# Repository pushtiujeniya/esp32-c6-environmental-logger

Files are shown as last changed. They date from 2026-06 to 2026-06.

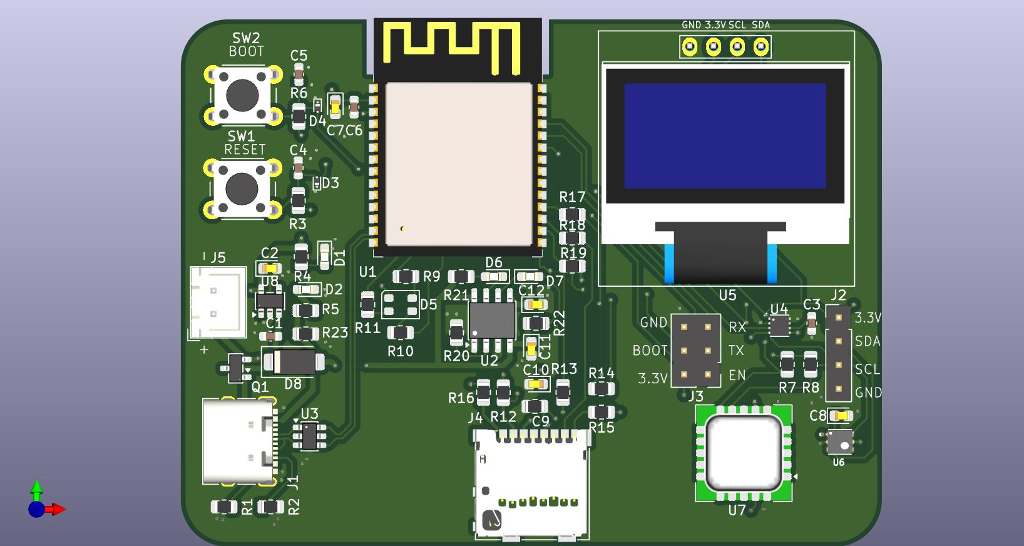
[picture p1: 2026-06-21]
3d view/3D_top view.jpg

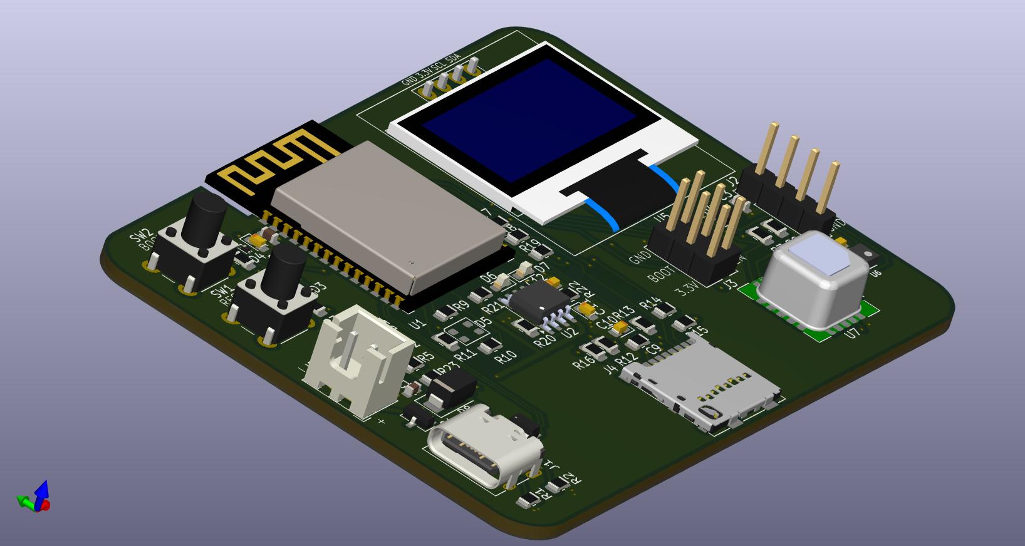
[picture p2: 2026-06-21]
3d view/3d_side view.jpg

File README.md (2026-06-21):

# ESP32-C6 Environmental Sensor Station & Data Logger

An open-source, 4-layer IoT environmental monitoring station and telemetry data logger powered by the **ESP32-C6-WROOM-1** microcontroller. This board utilizes multi-protocol wireless connectivity (Wi-Fi 6, BLE 5, and Zigbee/Thread) to read atmospheric and gas sensors, display local telemetry, and securely back up data to a local MicroSD card.

---

## 🛠 Core Features & Hardware

### 1. Processor & Wireless Connectivity
* **MCU:** ESP32-C6-WROOM-1
* **Programming/Debugging:** On-board dual-purpose interfaces for flashing and debugging via a protected USB-C 2.0 interface.
* 
### 2. Comprehensive Sensor Array
* **SCD41-D-R2:** Photoacoustic $CO_2$ sensor measuring true carbon dioxide levels in ppm ($I^2C$ Address: `0x62`).
* **SGP41-D-R4:** Digital gas sensor providing multi-pixel MOx sensing for VOC (Volatile Organic Compounds) and $NO_x$ (Nitrogen Oxides) indoor environmental indexes ($I^2C$ Address: `0x59`).
* **HDC2033:** Low-power, high-accuracy digital temperature and relative humidity sensor ($I^2C$ Address: `0x44`).

### 3. Storage & User Interface
* **MicroSD Card Slot:** Dedicated SPI-driven logging interface with individual inline trace damping resistors and pull-ups for secure local data logging.
* **OLED Display (SSD1306):** 0.96" $I^2C$ graphic display panel for live visual terminal outputs and local troubleshooting ($I^2C$ Address: `0x3C`).

### 4. Power & Battery Management
* **Charging:** TP4056 lithium battery management IC with automated charge/discharging  indicator LEDs.
* **Power Path Switching:** Automated hardware power routing utilizing an AO3401A P-Channel MOSFET to seamlessly switch between USB power and Battery power.
* **Regulator:** AP2112K-3.3V Ultra-low dropout, low-noise LDO regulator supplying clean $3.3\text{V}$ power rails up to $600\text{mA}$ to the wireless MCU and sensors.

### 5. Push Button Switch
* **Reset switch** A button with ESD protection  to reset the MCU 
* **BOOT switch** A BOOT switch button to enter into bootloading mode for new firmware flashing
  
### 5. I2C and UART Pin Connector
* External i2c pin header
* External UART pin header  

---

## 🎛 4-Layer PCB Stackup Architecture

This board is structured with an optimized 4-layer stackup:

* **Layer 1 (Top Copper - F.Cu):** High-speed digital signals, data busses ($I^2C$, SPI), and  component placement.
* **Layer 2 (Internal Plane 1 - In1.Cu):** Solid Ground Plane (GND) providing direct, uninterrupted return paths for low EMI noise and optimal RF shielding.
* **Layer 3 (Internal Plane 2 - In2.Cu):** Split Power Plane ($+5\text{V}$, $+3.3\text{V}$, $\text{VBAT}$) providing low-impedance power distribution directly below signal lines.
* **Layer 4 (Bottom Copper - B.Cu):** Secondary signal traces and clean copper pours for thermal dissipation.

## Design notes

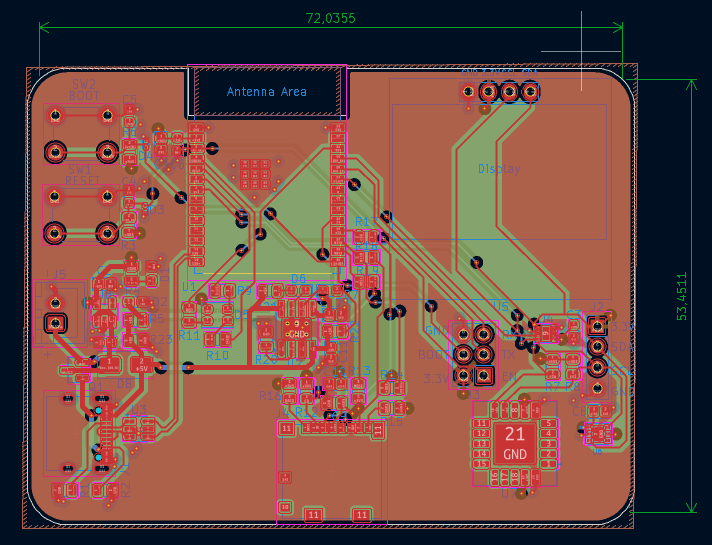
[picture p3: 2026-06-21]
layout images/Screenshot 2026-06-21 155718.png

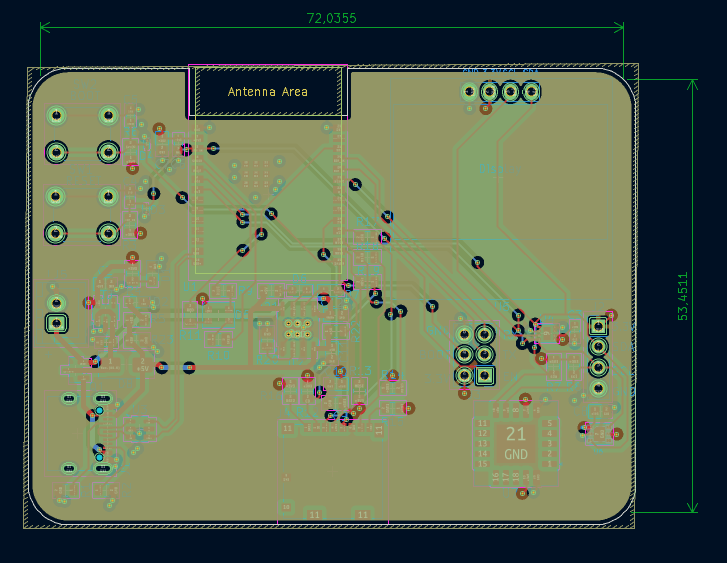
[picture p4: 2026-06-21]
layout images/Screenshot 2026-06-21 155729.png

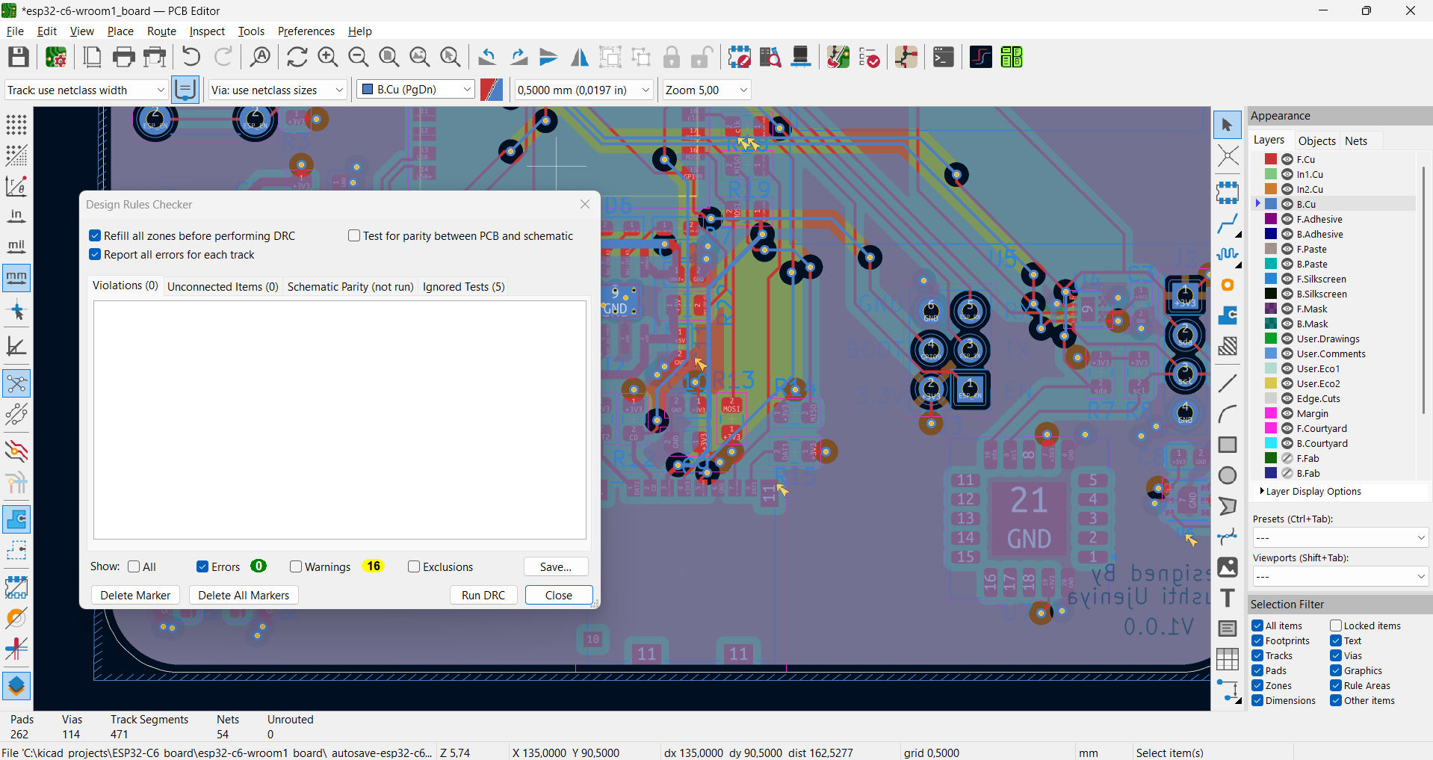
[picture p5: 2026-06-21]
layout images/Screenshot 2026-06-21 132708.png

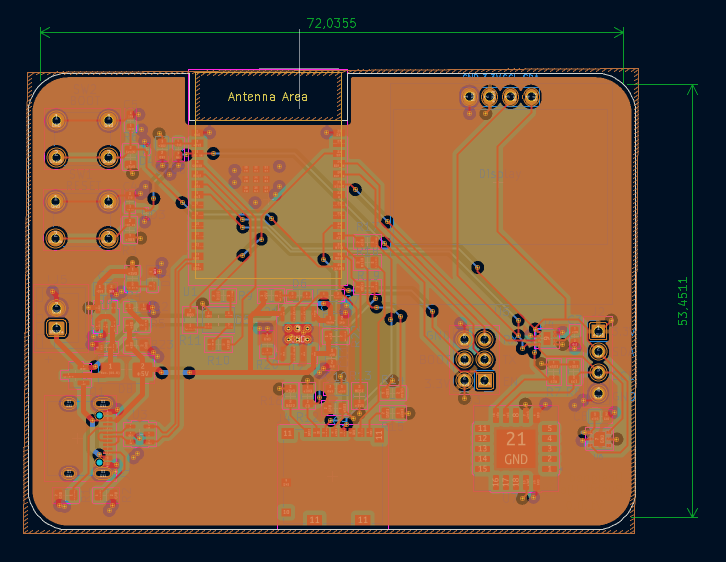
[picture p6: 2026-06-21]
layout images/Screenshot 2026-06-21 155738.png

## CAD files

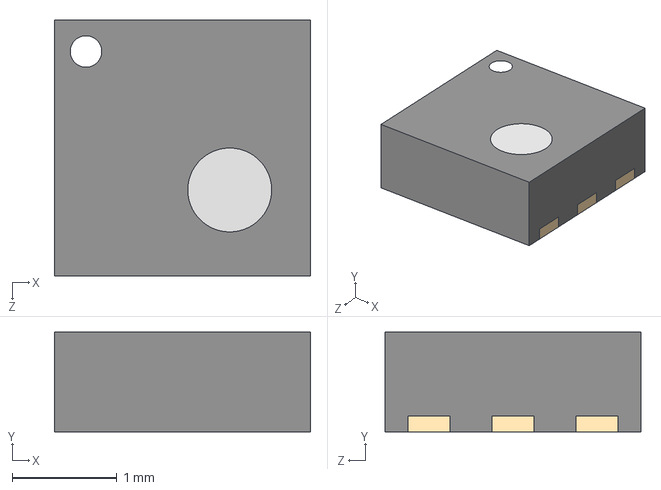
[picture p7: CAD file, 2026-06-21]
external library/SGP41-D-R4--3DModel-STEP-56544.STEP
2.44 x 0.95 x 2.44 mm

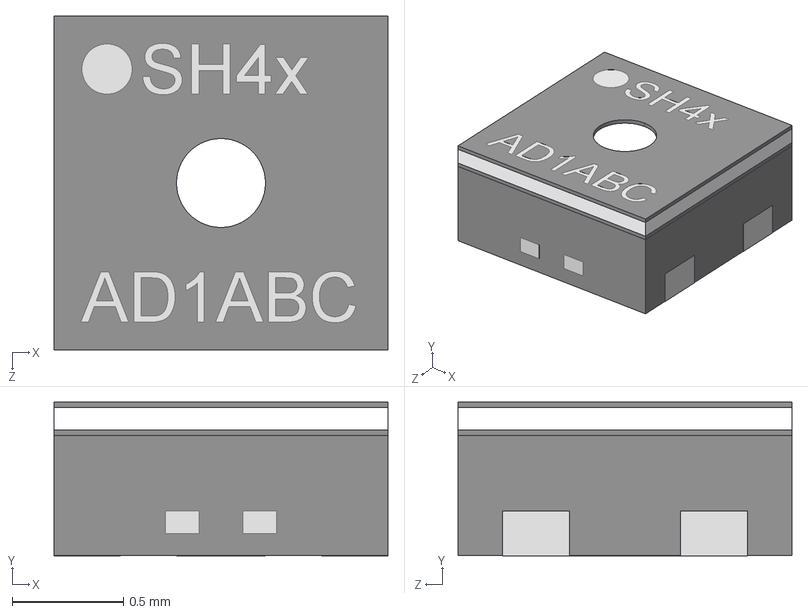
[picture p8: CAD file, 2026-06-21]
external library/SHT41-AD1B-R2--3DModel-STEP-369182.STEP
1.50 x 0.691 x 1.50 mm

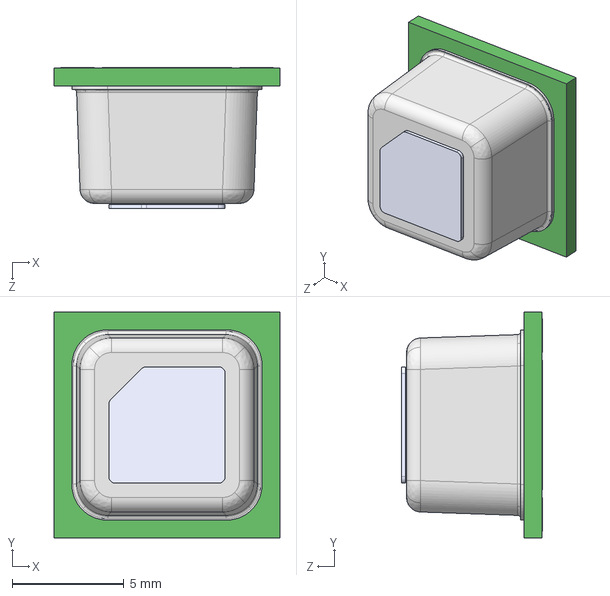
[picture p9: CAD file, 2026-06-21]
external library/SCD41-D-R2--3DModel-STEP-369182.STEP
10.1 x 10.1 x 6.31 mm

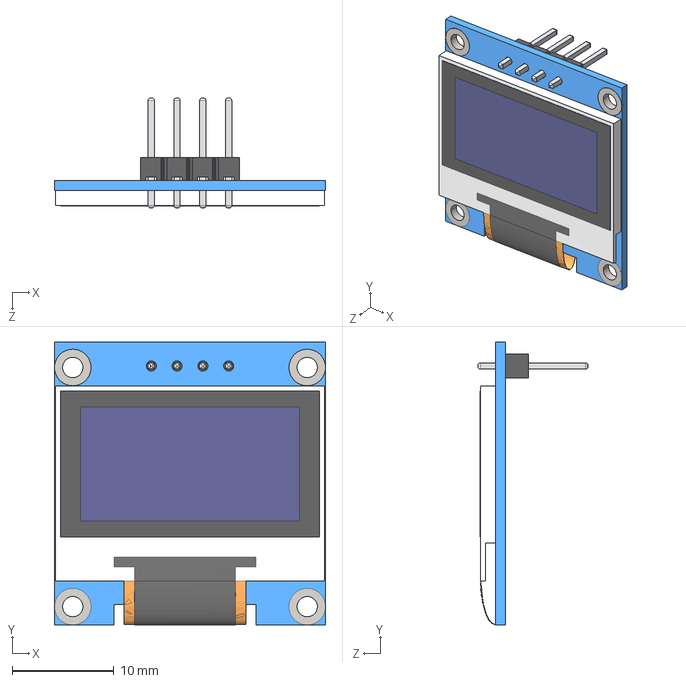
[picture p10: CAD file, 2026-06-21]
external library/OLED 128x64.STP
26.7 x 27.9 x 10.8 mm

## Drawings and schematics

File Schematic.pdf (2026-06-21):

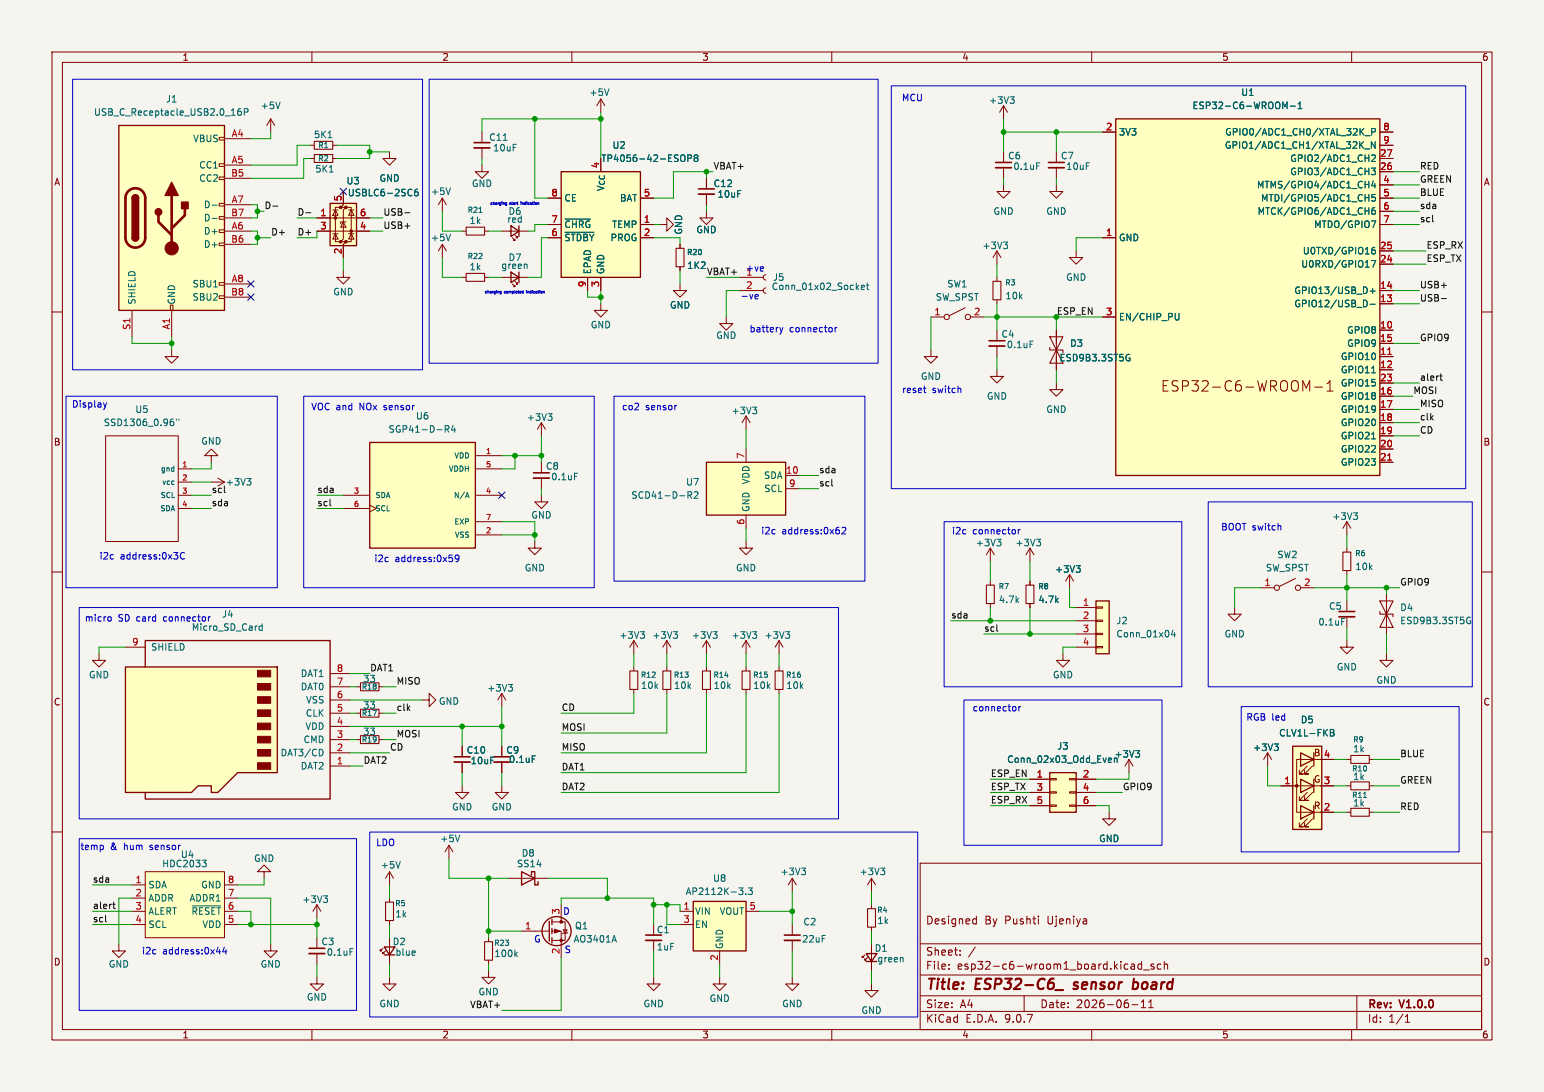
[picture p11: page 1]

3 BAT 5 TEMP 1 PROG 2 GND GND

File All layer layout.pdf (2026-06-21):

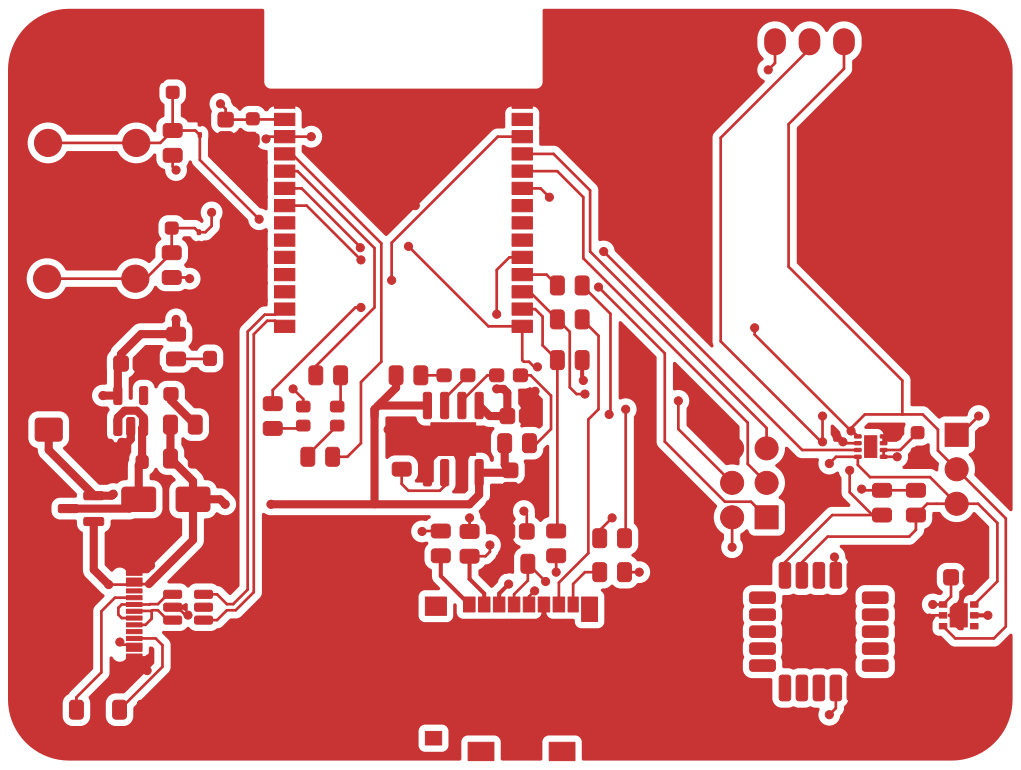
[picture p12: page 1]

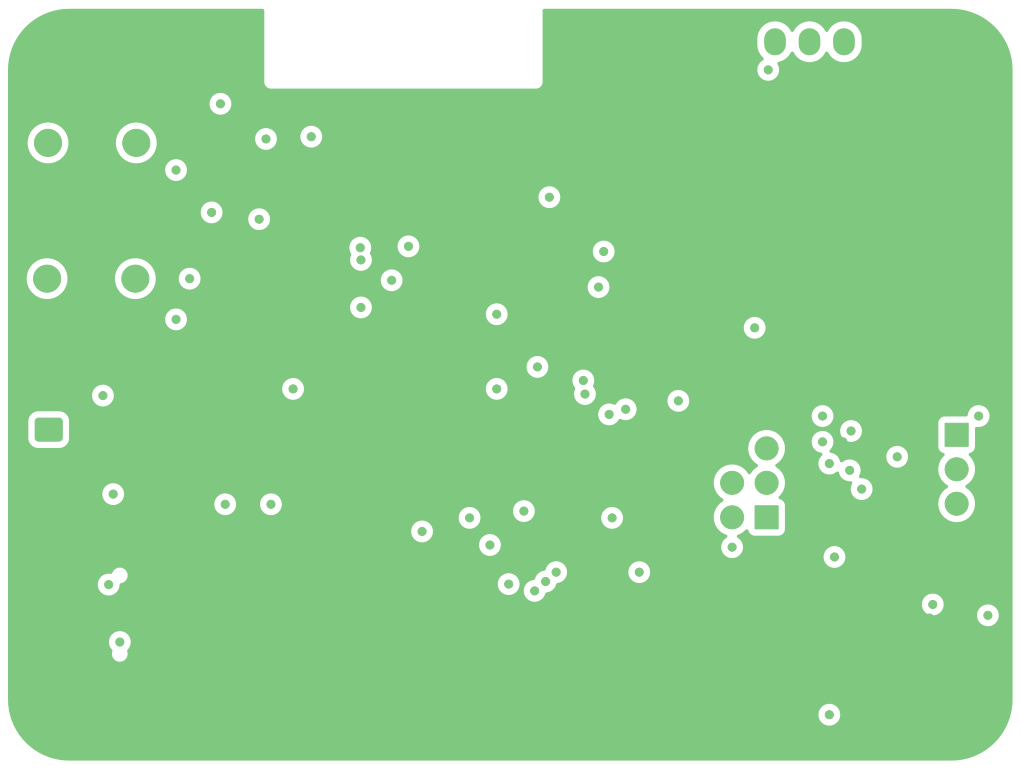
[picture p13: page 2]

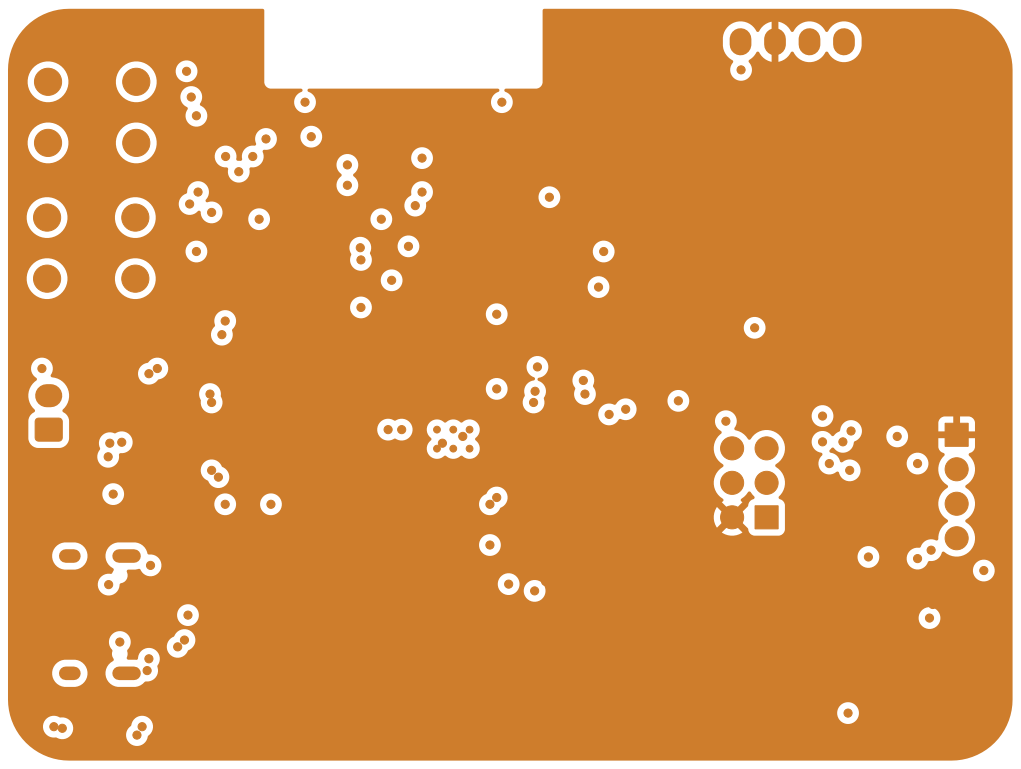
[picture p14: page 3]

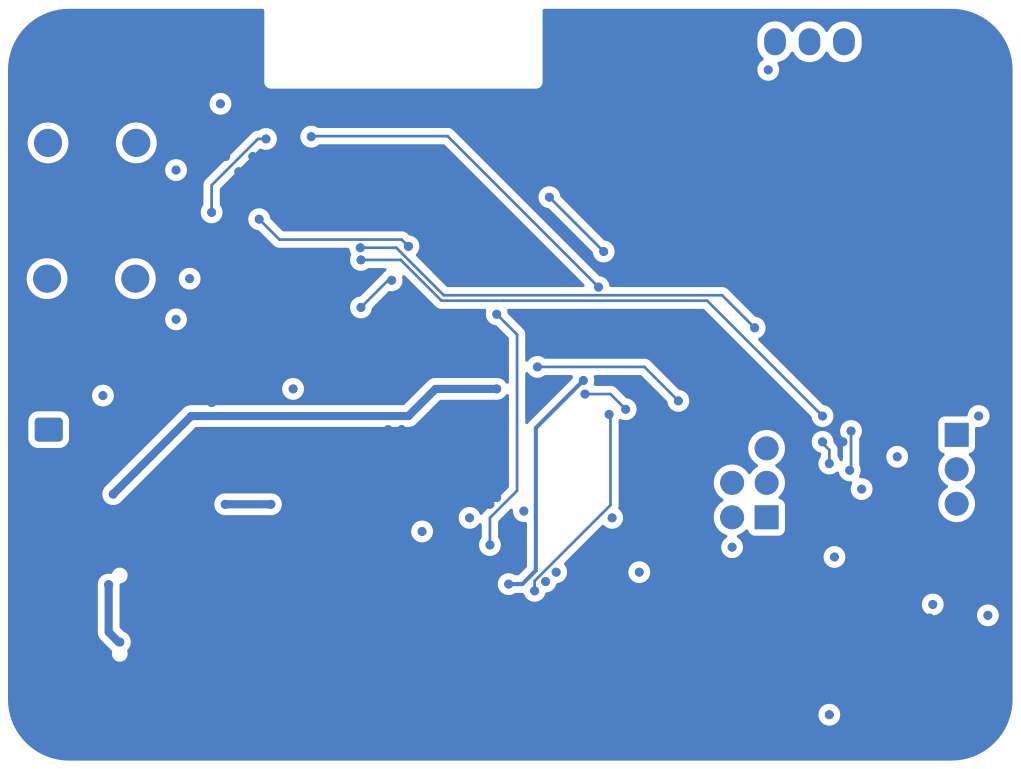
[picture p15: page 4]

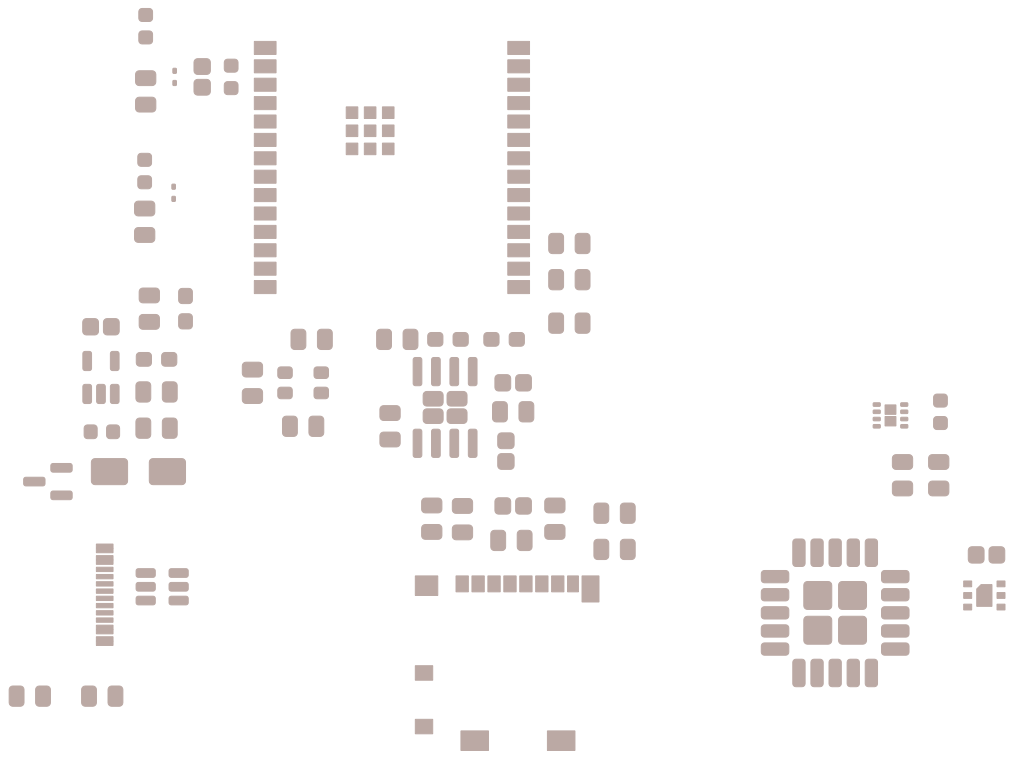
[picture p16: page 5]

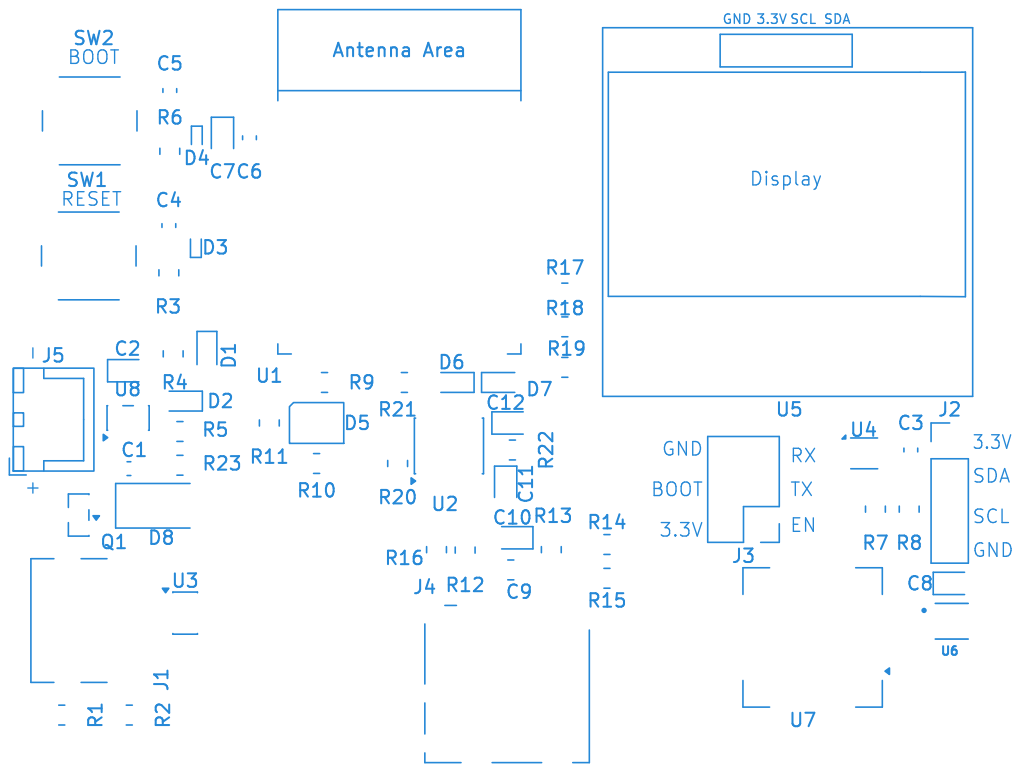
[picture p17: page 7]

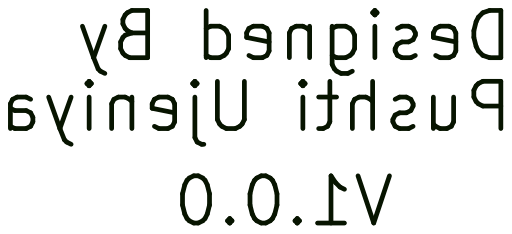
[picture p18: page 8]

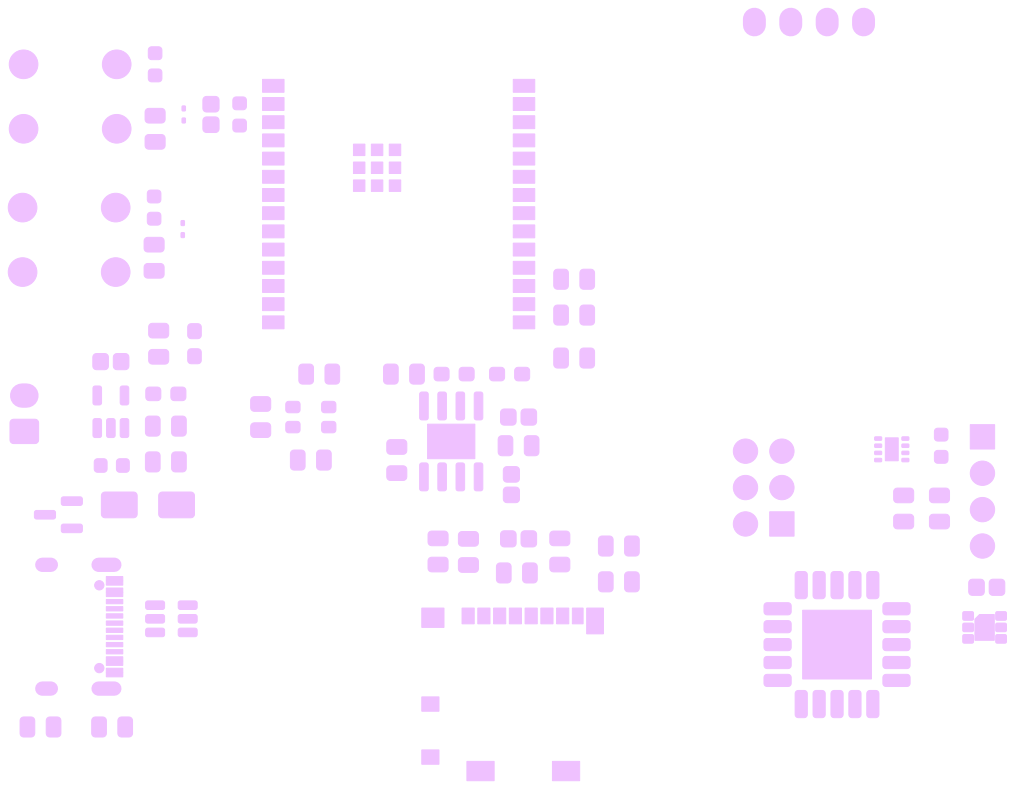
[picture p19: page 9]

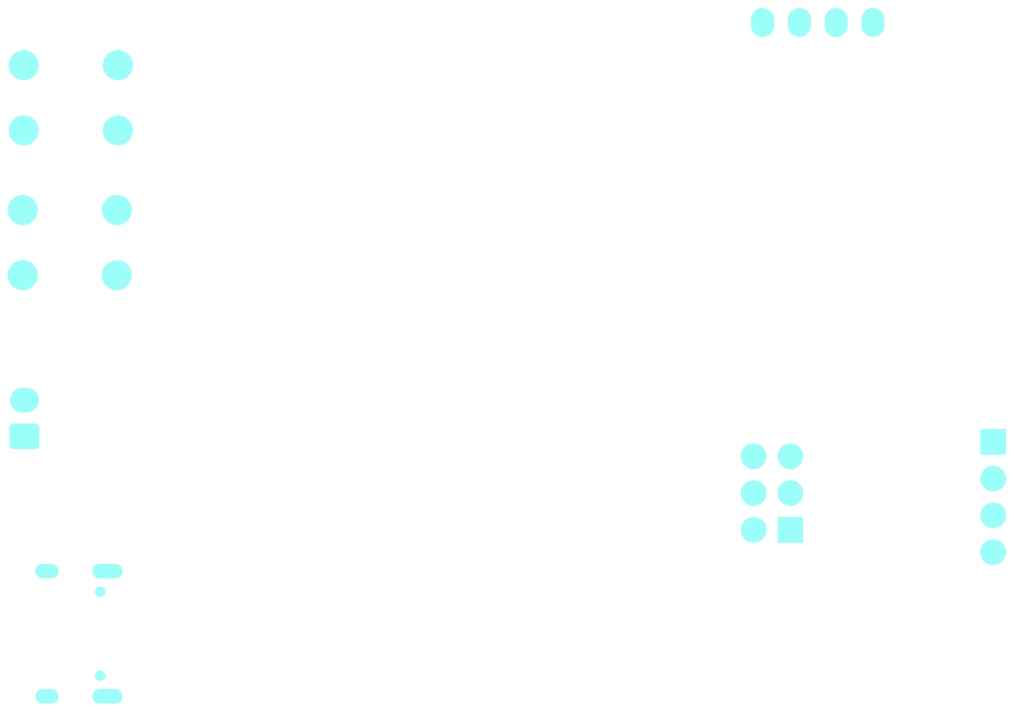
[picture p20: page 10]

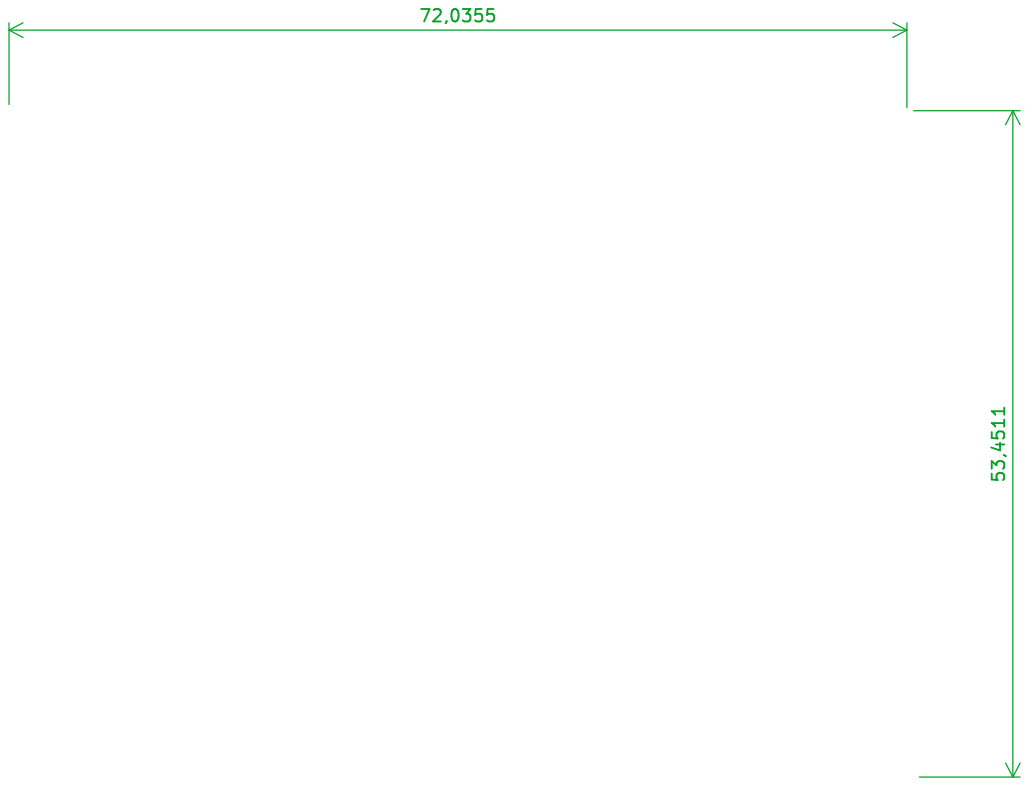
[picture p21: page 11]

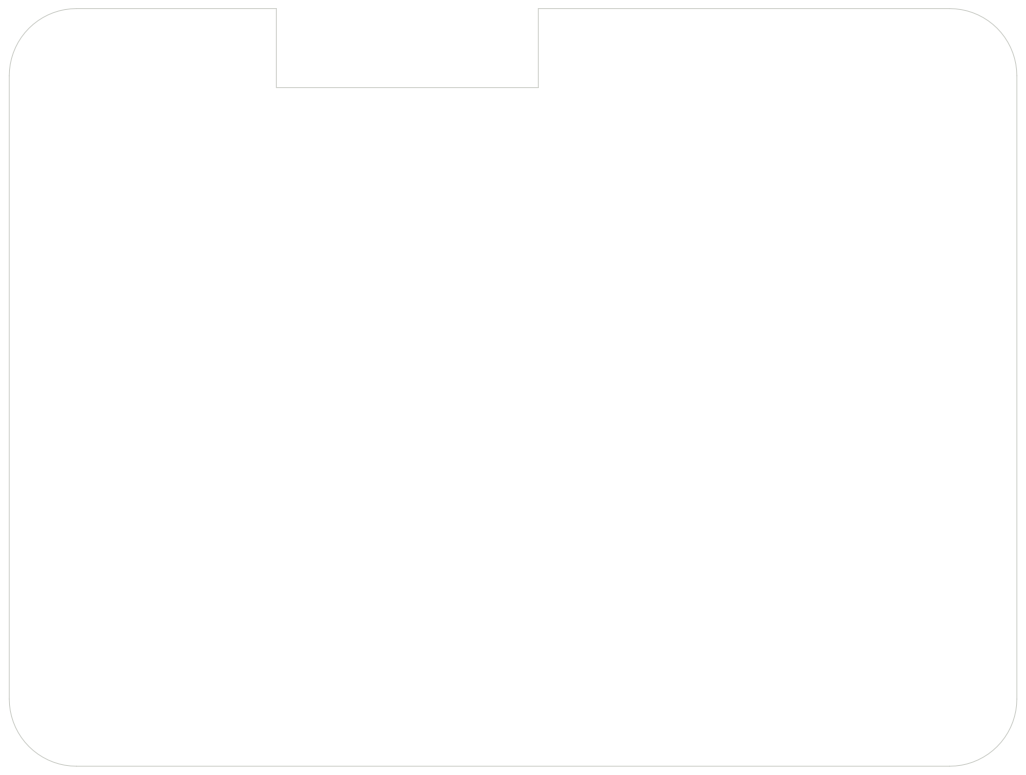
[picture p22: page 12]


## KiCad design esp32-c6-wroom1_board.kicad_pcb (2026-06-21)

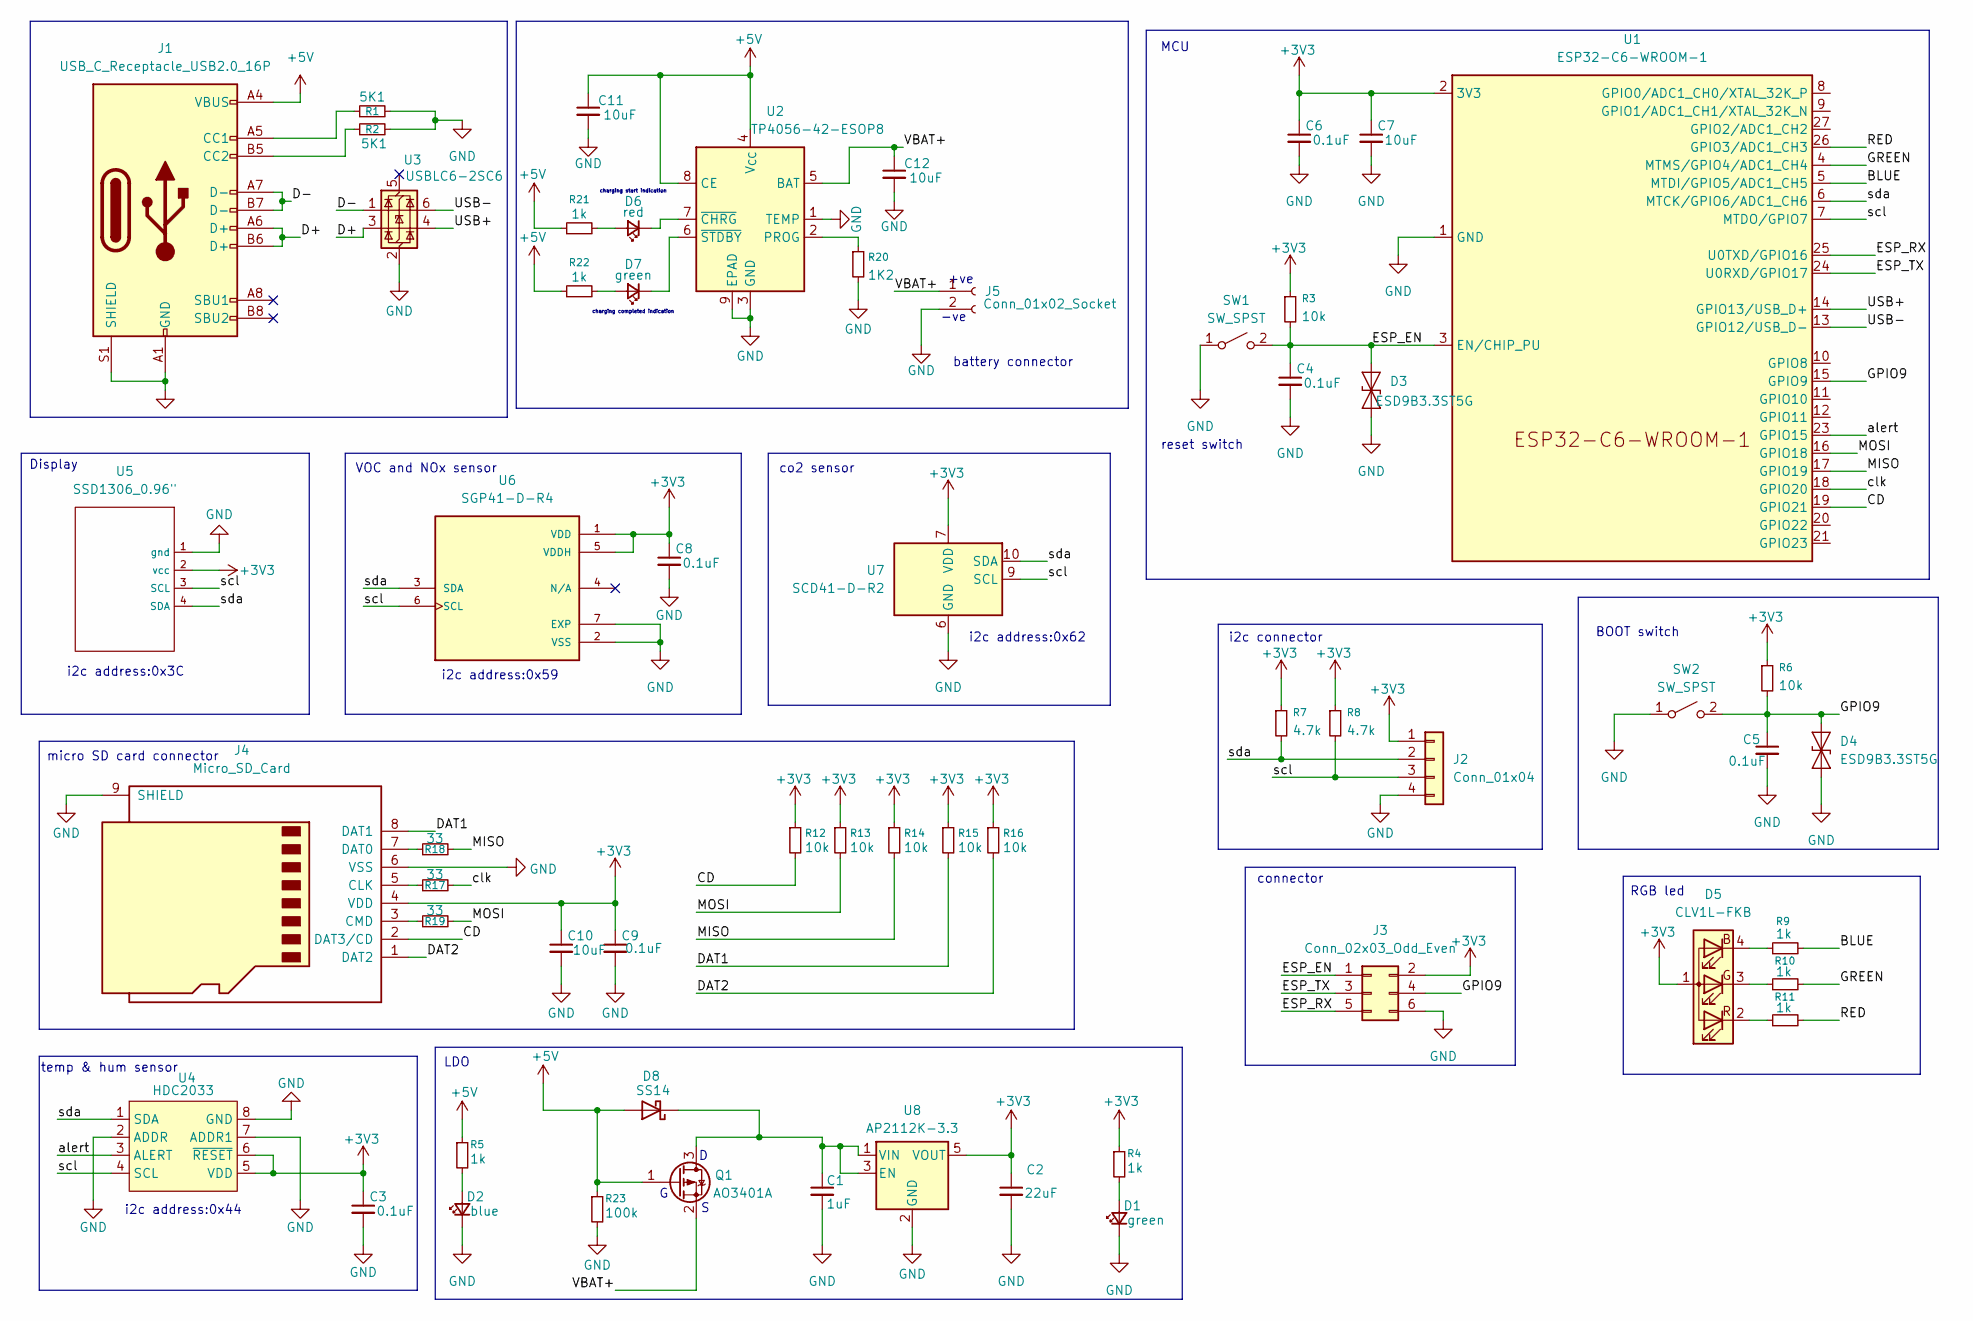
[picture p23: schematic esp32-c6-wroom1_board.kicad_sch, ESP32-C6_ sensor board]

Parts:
C1: 1uF; C_0603_1608Metric
C2: 22uF; CP_EIA-1608-08_AVX-J
C3, C4, C5, C6: 0.1uF; C_0603_1608Metric
C7, C10, C11, C12: 10uF; CP_EIA-1608-08_AVX-J
C8: 0.1uF; CP_EIA-1608-08_AVX-J
C9: 0.1uF; R_0805_2012Metric
D1, D7: green; LED_0603_1608Metric_Pad1.05x0.95mm_HandSolder
D2: blue; LED_0603_1608Metric_Pad1.05x0.95mm_HandSolder
D3, D4: ESD9B3.3ST5G; D_SOD-923
D5: CLV1L-FKB; LED_Cree-PLCC4_3.2x2.8mm_CCW
D6: red; LED_0603_1608Metric_Pad1.05x0.95mm_HandSolder
D8: SS14; D_SMA
J1: USB_C_Receptacle_USB2.0_16P; USB_C_Receptacle_XKB_U262-16XN-4BVC11
J2: Conn_01x04; PinHeader_1x04_P2.54mm_Vertical
J3: Conn_02x03_Odd_Even; PinHeader_2x03_P2.54mm_Vertical
J4: Micro_SD_Card; microSD_HC_Molex_104031-0811
J5: Conn_01x02_Socket; JST_XH_B2B-XH-A_1x02_P2.50mm_Vertical
Q1: AO3401A; SOT-23
R1, R2: 5K1; R_0805_2012Metric
R3, R6, R12, R13, R14, R15, R16: 10k; R_0805_2012Metric
R4, R5, R9, R10, R11, R21, R22: 1k; R_0805_2012Metric
R7, R8: 4.7k; R_0805_2012Metric
R17, R18, R19: 33; R_0805_2012Metric
R20: 1K2; R_0805_2012Metric
R23: 100k; R_0805_2012Metric
SW1, SW2: SW_SPST; SW_PUSH_6mm_H8mm
U1: ESP32-C6-WROOM-1
U2: TP4056-42-ESOP8; SOIC-8-1EP_3.9x4.9mm_P1.27mm_EP2.41x3.3mm_ThermalVias
U3: USBLC6-2SC6; SOT-23-6
U4: HDC2033; WSON-8-1EP_2x2mm_P0.5mm_EP0.9x1.6mm
U5: SSD1306_0.96"; 128x64OLED
U6: SGP41-D-R4; XDCR_SGP41-D-R4; PARTREV 1.0
U7: SCD41-D-R2; Sensirion_SCD4x-1EP_10.1x10.1mm_P1.25mm_EP4.8x4.8mm
U8: AP2112K-3.3; SOT-23-5

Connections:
+3V3: C2.1, C3.1, C6.1, C7.1, C8.1, C9.1, C10.1, D5.1 (A), J2.1, J3.2, J4.4 (VDD), R3.1, R4.1, R6.1, R7.1, R8.1, R12.1, R13.1, R14.1, R15.1, R16.1, U1.2 (3V3), U4.5 (VDD), U4.6 (~RESET), U5.2 (vcc), U6.1 (VDD), U6.5 (VDDH), U7.7 (VDD), U7.19 (VDD), U8.5 (VOUT)
+5V: C11.1, D8.2 (A), J1.A4 (VBUS), J1.A9 (VBUS), J1.B4 (VBUS), J1.B9 (VBUS), Q1.1 (G), R5.1, R21.1, R22.1, R23.1, U2.4 (V_{CC}), U2.8 (CE)
/BLUE: R9.2, U1.5 (MTDI/GPIO5/ADC1_CH5)
/CD: J4.2 (DAT3/CD), R12.2, U1.19 (GPIO21)
/D+: J1.A6 (D+), J1.B6 (D+), U3.3 (I/O2)
/D-: J1.A7 (D-), J1.B7 (D-), U3.1 (I/O1)
/DAT1: J4.8 (DAT1), R15.2
/DAT2: J4.1 (DAT2), R16.2
/ESP_EN: C4.1, D3.2 (A2), J3.1, R3.2, SW1.2 (B), U1.3 (EN/CHIP_PU)
/ESP_RX: J3.5, U1.25 (U0TXD/GPIO16)
/ESP_TX: J3.3, U1.24 (U0RXD/GPIO17)
/GPIO9: C5.1, D4.2 (A2), J3.4, R6.2, SW2.2 (B), U1.15 (GPIO9)
/GREEN: R10.2, U1.4 (MTMS/GPIO4/ADC1_CH4)
/MISO: R14.2, R18.2, U1.17 (GPIO19)
/MOSI: R13.2, R19.2, U1.16 (GPIO18)
/RED: R11.2, U1.26 (GPIO3/ADC1_CH3)
/USB+: U1.14 (GPIO13/USB_D+), U3.4 (I/O2)
/USB-: U1.13 (GPIO12/USB_D-), U3.6 (I/O1)
/VBAT+: C12.1, J5.1, Q1.2 (S), U2.5 (BAT)
/alert: U1.23 (GPIO15), U4.3 (ALERT)
/clk: R17.2, U1.18 (GPIO20)
/scl: J2.3, R8.2, U1.7 (MTDO/GPIO7), U4.4 (SCL), U5.3 (SCL), U6.6 (SCL), U7.9 (SCL)
/sda: J2.2, R7.2, U1.6 (MTCK/GPIO6/ADC1_CH6), U4.1 (SDA), U5.4 (SDA), U6.3 (SDA), U7.10 (SDA)
GND: C1.2, C2.2, C3.2, C4.2, C5.2, C6.2, C7.2, C8.2, C9.2, C10.2, C11.2, C12.2, D1.1 (K), D2.1 (K), D3.1 (A1), D4.1 (A1), J1.A1 (GND), J1.A12 (GND), J1.B1 (GND), J1.B12 (GND), J1.S1 (SHIELD), J2.4, J3.6, J4.6 (VSS), J4.9 (SHIELD), J5.2, R1.2, R2.2, R20.2, R23.2, SW1.1 (A), SW2.1 (A), U1.1 (GND), U1.28 (GND), U1.29 (GND), U2.1 (TEMP), U2.3 (GND), U2.9 (EPAD), U3.2 (GND), U4.2 (ADDR), U4.7 (ADDR1), U4.8 (GND), U5.1 (gnd), U6.2 (VSS), U6.7 (EXP), U7.6 (GND), U7.20 (GND), U7.21 (GND), U8.2 (GND)
unnamed: D1.2 (A), R4.2
unnamed: D2.2 (A), R5.2
unnamed: D5.4 (BK), R9.1
unnamed: D5.3 (GK), R10.1
unnamed: D5.2 (RK), R11.1
unnamed: D6.2 (A), R21.2
unnamed: D6.1 (K), U2.7 (~CHRG)
unnamed: D7.2 (A), R22.2
unnamed: D7.1 (K), U2.6 (~STDBY)
unnamed: C1.1, D8.1 (K), Q1.3 (D), U8.1 (VIN), U8.3 (EN)
unnamed: J1.A5 (CC1), R1.1
unnamed: J1.B5 (CC2), R2.1
unnamed: J4.5 (CLK), R17.1
unnamed: J4.3 (CMD), R19.1
unnamed: J4.7 (DAT0), R18.1
unnamed: R20.1, U2.2 (PROG)

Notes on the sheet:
+ve
temp & hum sensor
i2c connector
micro SD card connector
charging completed indication
BOOT switch
VOC and NOx sensor
RGB led
Display
connector
LDO
i2c address:0x3C
charging start indication
reset switch
battery connector
i2c address:0x62
co2 sensor
MCU
i2c address:0x44
-ve
i2c address:0x59

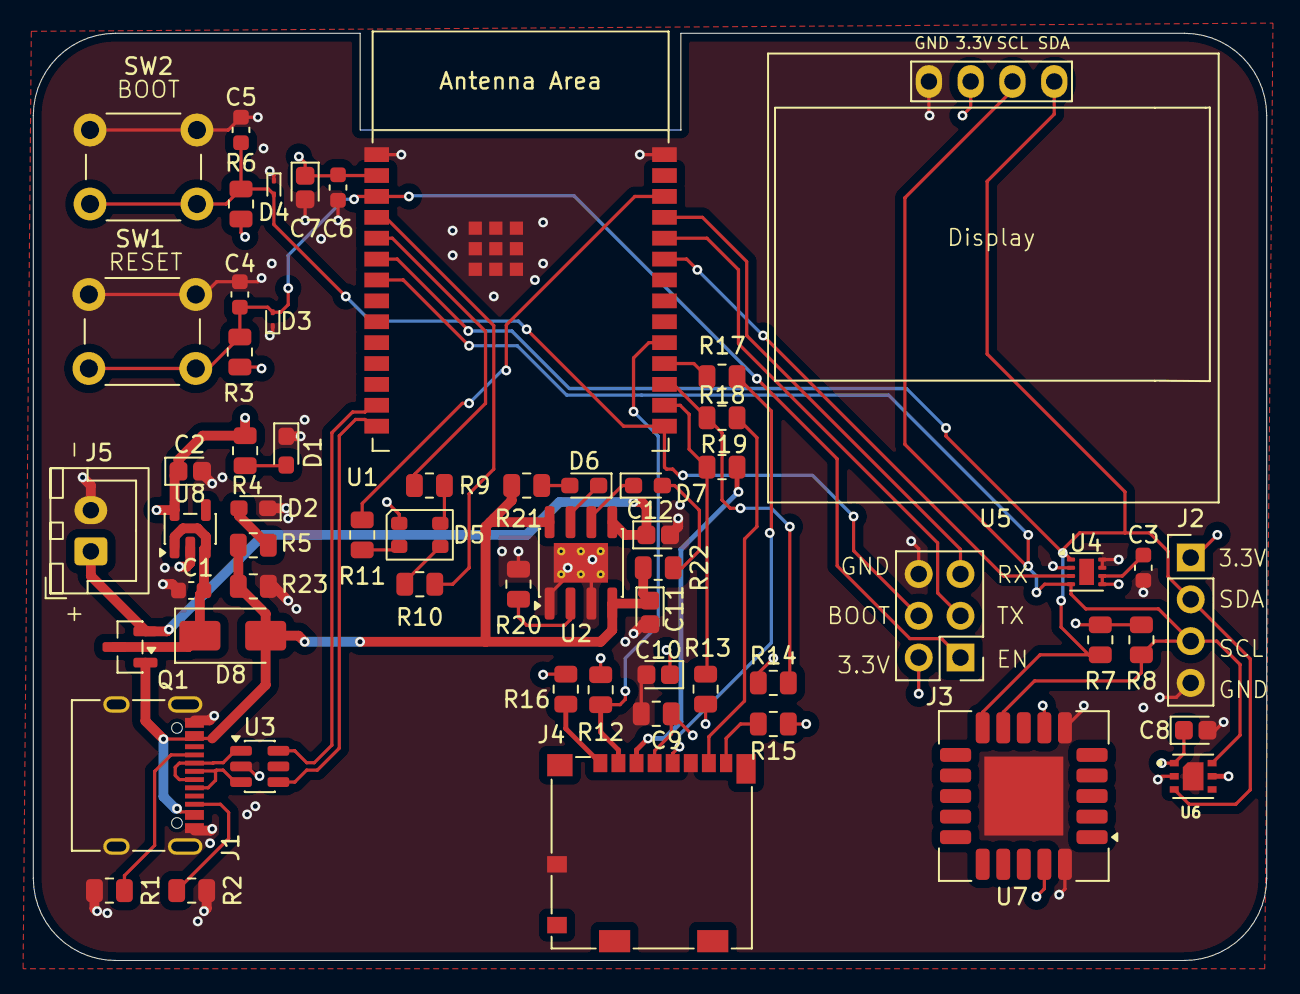
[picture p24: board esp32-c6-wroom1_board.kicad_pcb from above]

Board: 4 copper layers, 75.0 x 56.4 mm, 59 parts (0 on the bottom side), 40 nets.

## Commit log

2026-06-21 Enhance README with detailed project specifications
    Expanded the README to include detailed features, hardware specifications, and PCB architecture for the ESP32-C6 Environmental Sensor Station.
2026-06-21 schematic pdf added
2026-06-21 project files added
    [esp32-c6-wroom1_board.kicad_pcb, esp32-c6-wroom1_board.kicad_sch]
2026-06-21 Update README with new hardware features
    Added sections for Push Button Switch and I2C/UART Pin Connector.
2026-06-21 external library added
    [OLED 128x64.STP, SCD41-D-R2--3DModel-STEP-369182.STEP, SGP41-D-R4--3DModel-STEP-56544.STEP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]
